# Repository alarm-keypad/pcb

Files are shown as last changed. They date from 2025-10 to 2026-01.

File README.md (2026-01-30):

# Alarm keypad PCB

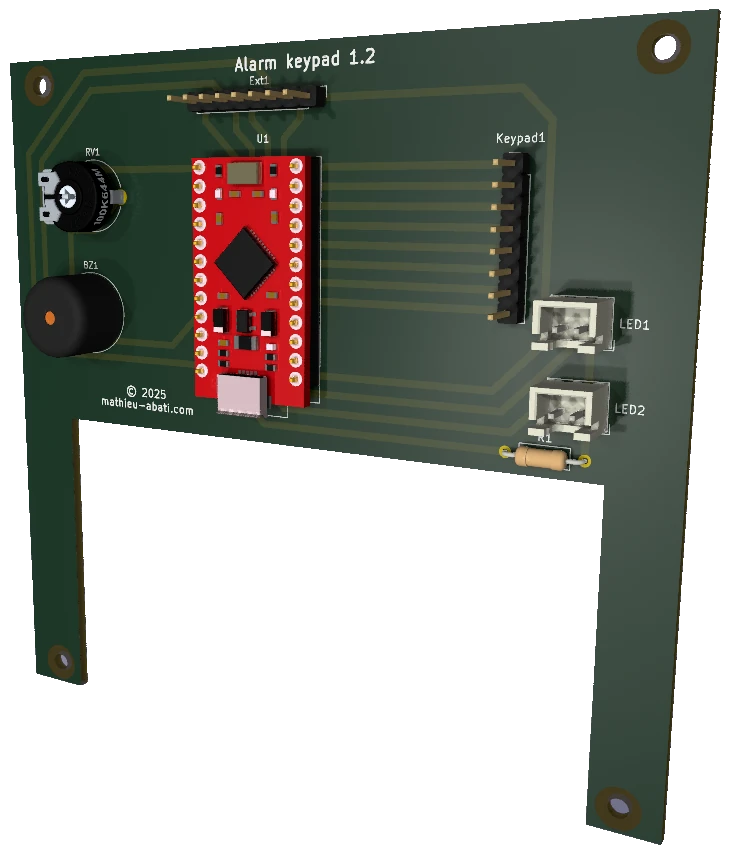
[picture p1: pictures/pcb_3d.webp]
PCB 3D view


KiCad project for alarm keypad PCB.

You can find a firmware designed to run on this board [on the dedicated repository](https://github.com/alarm-keypad/firmware).

## Required parts

- Resistor for LEDs (value depends on wanted brightness)
- Buzzer (active, 5V, model depends of wanted sound)
- Potentiometer for buzzer (to set sound level)
- Arduino Pro Micro (5V)
- 2x JST connector 1x02 2.50mm pitch (for case mounted LED)
- 2x 2.54mm 8 pins female connectors

## Integration

It is designed to be installed in an aluminium junction box 40x100x110mm.
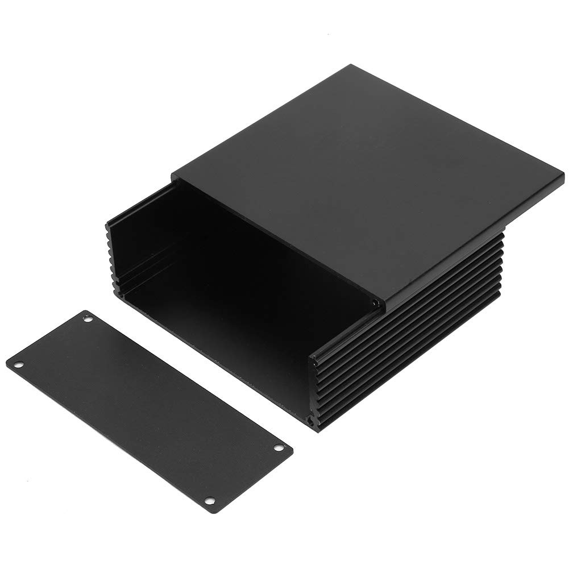
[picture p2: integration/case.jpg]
Case


You can use different kind of keypads, for example:
- Tru Components 4x3, or 4x4 (with A, B, C, D letters),
- Membrane matrix 4x4.

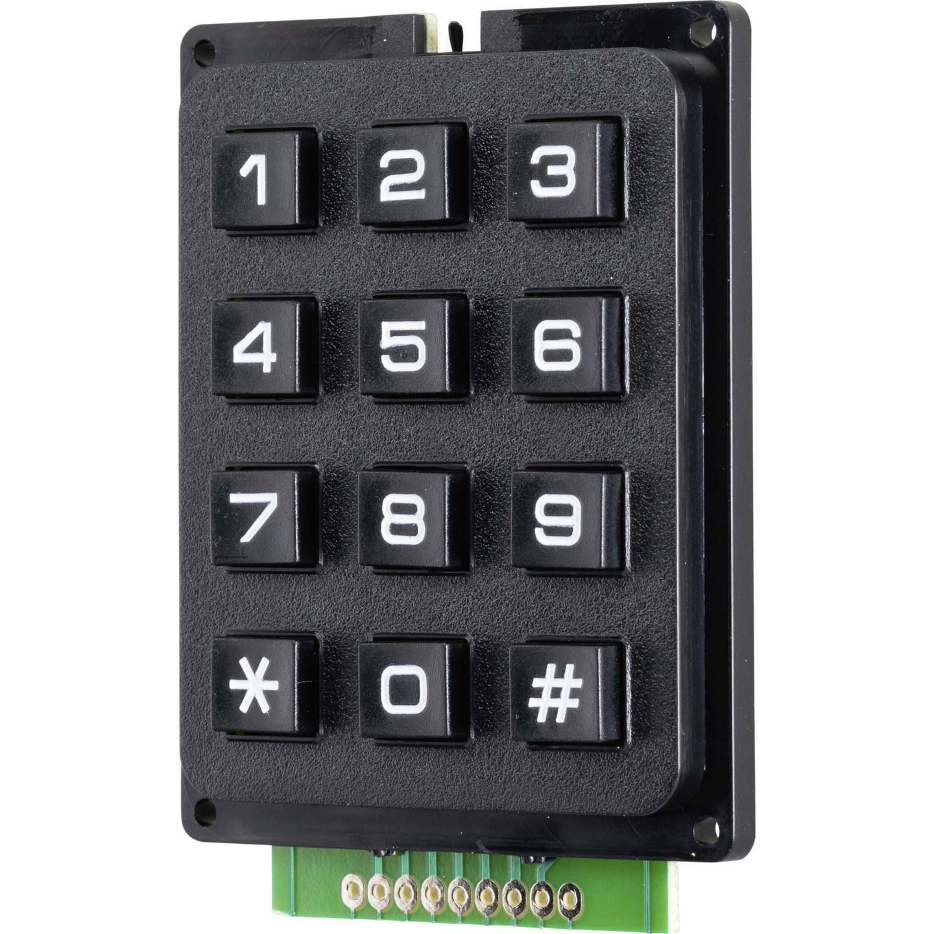
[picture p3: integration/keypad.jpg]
Tru Components 4x3

Tru Components 4x3 can be integrated in the case using the following resources.
See [drill and cut file](integration/keypad_drill_cut.pdf) to prepare the case.
Then you can use [this 3D printable border](integration/keypad_border.stl) to
make its integration clean.
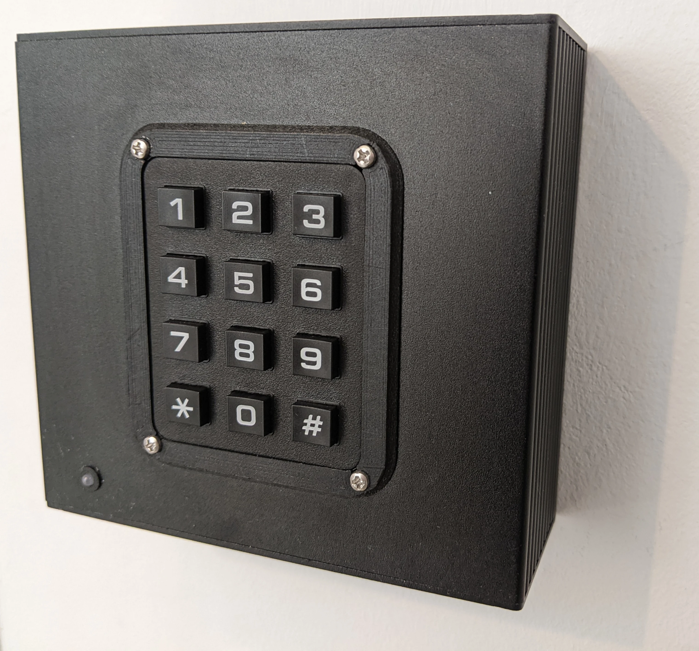
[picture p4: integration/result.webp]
Integration result


## KiCAD project

Arduino Pro Micro KiCAD files can be downloaded
[from this GitHub repository](https://github.com/g200kg/kicad-lib-arduino).

Piher PT-10 potentiometer 3D model can be downloaded
[from grabcad](https://grabcad.com/library/piher-pt-10-1).
Its scale has to be divided by 10.

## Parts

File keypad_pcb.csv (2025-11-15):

Source: | /home/mathieu/Documents/HomeAssistant/keypad/cad/keypad_pcb/keypad_pcb.kicad_sch
Date: | ven. 07 avril 2023 15:16:09
Tool: | Eeschema (6.0.9)
Generator: | /usr/share/kicad/plugins/bom_csv_grouped_by_value.py
Component Count: | 8
Individual Components:
Item | Qty | Reference(s) | Value | LibPart | Footprint | Datasheet
 |  | A1 | Arduino_Nano_v3.x | MCU_Module:Arduino_Nano_v3.x | Module:Arduino_Nano | http://www.mouser.com/pdfdocs/Gravitech_Arduino_Nano3_0.pdf
 |  | BZ1 | Buzzer | Device:Buzzer | Buzzer_Beeper:Buzzer_12x9.5RM7.6 | ~
 |  | Ext1 | Conn_01x08 | Connector_Generic:Conn_01x08 | Connector_PinHeader_2.54mm:PinHeader_1x08_P2.54mm_Vertical | ~
 |  | Keypad1 | Conn_01x08 | Connector_Generic:Conn_01x08 | Connector_PinHeader_2.54mm:PinHeader_1x08_P2.54mm_Vertical | ~
 |  | LED1 | Conn_01x02 | Connector_Generic:Conn_01x02 | Connector_JST:JST_XH_B2B-XH-A_1x02_P2.50mm_Vertical | ~
 |  | LED2 | Conn_01x02 | Connector_Generic:Conn_01x02 | Connector_JST:JST_XH_B2B-XH-A_1x02_P2.50mm_Vertical | ~
 |  | R1 | R | Device:R | Resistor_THT:R_Axial_DIN0207_L6.3mm_D2.5mm_P10.16mm_Horizontal | ~
 |  | RV1 | R_Potentiometer | Device:R_Potentiometer | Potentiometer_THT:Potentiometer_Piher_PT-10-V10_Vertical | ~
Collated Components:
Item | Qty | Reference(s) | Value | LibPart | Footprint | Datasheet
1 | 1 | A1 | Arduino_Nano_v3.x | MCU_Module:Arduino_Nano_v3.x | Module:Arduino_Nano | http://www.mouser.com/pdfdocs/Gravitech_Arduino_Nano3_0.pdf
2 | 1 | BZ1 | Buzzer | Device:Buzzer | Buzzer_Beeper:Buzzer_12x9.5RM7.6 | ~
3 | 2 | Ext1, Keypad1 | Conn_01x08 | Connector_Generic:Conn_01x08 | Connector_PinHeader_2.54mm:PinHeader_1x08_P2.54mm_Vertical | ~
4 | 2 | LED1, LED2 | Conn_01x02 | Connector_Generic:Conn_01x02 | Connector_JST:JST_XH_B2B-XH-A_1x02_P2.50mm_Vertical | ~
5 | 1 | R1 | R | Device:R | Resistor_THT:R_Axial_DIN0207_L6.3mm_D2.5mm_P10.16mm_Horizontal | ~
6 | 1 | RV1 | R_Potentiometer | Device:R_Potentiometer | Potentiometer_THT:Potentiometer_Piher_PT-10-V10_Vertical | ~

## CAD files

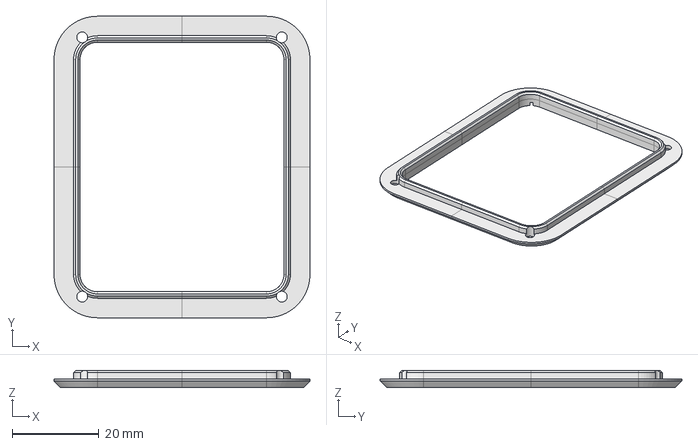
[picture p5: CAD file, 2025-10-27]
integration/keypad_border.FCStd
59.0 x 69.5 x 4.00 mm

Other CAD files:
integration/keypad_border.stl

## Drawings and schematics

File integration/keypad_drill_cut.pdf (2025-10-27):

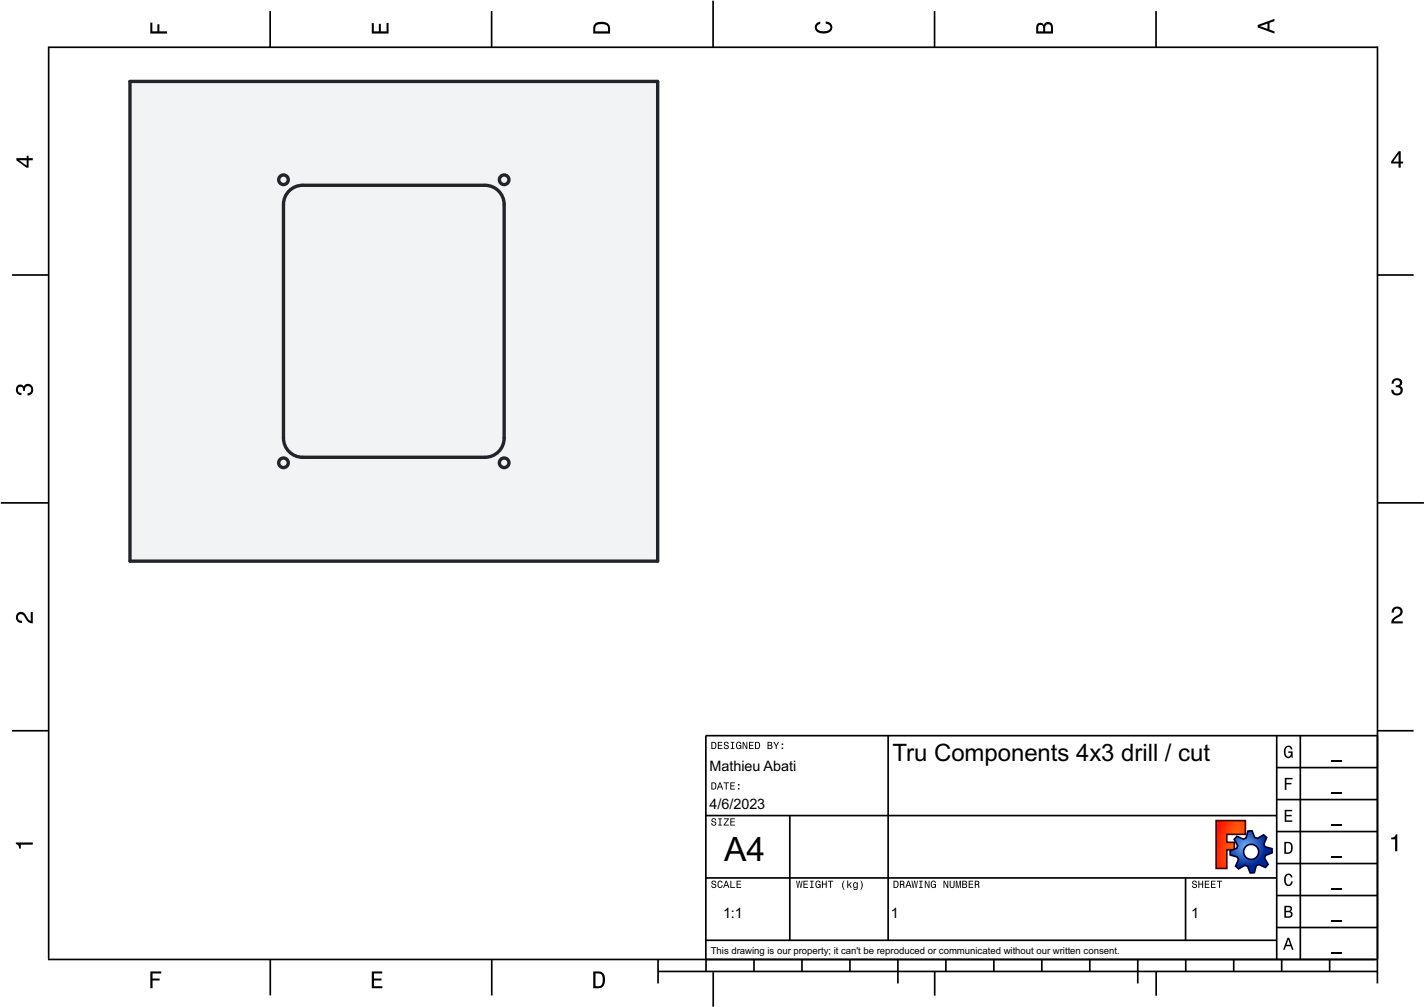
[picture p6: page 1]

Mathieu Abati 4/6/2023 | Tru Components 4x3 drill / cut

This drawing is our property; it can't be reproduced or communicated without our written consent.

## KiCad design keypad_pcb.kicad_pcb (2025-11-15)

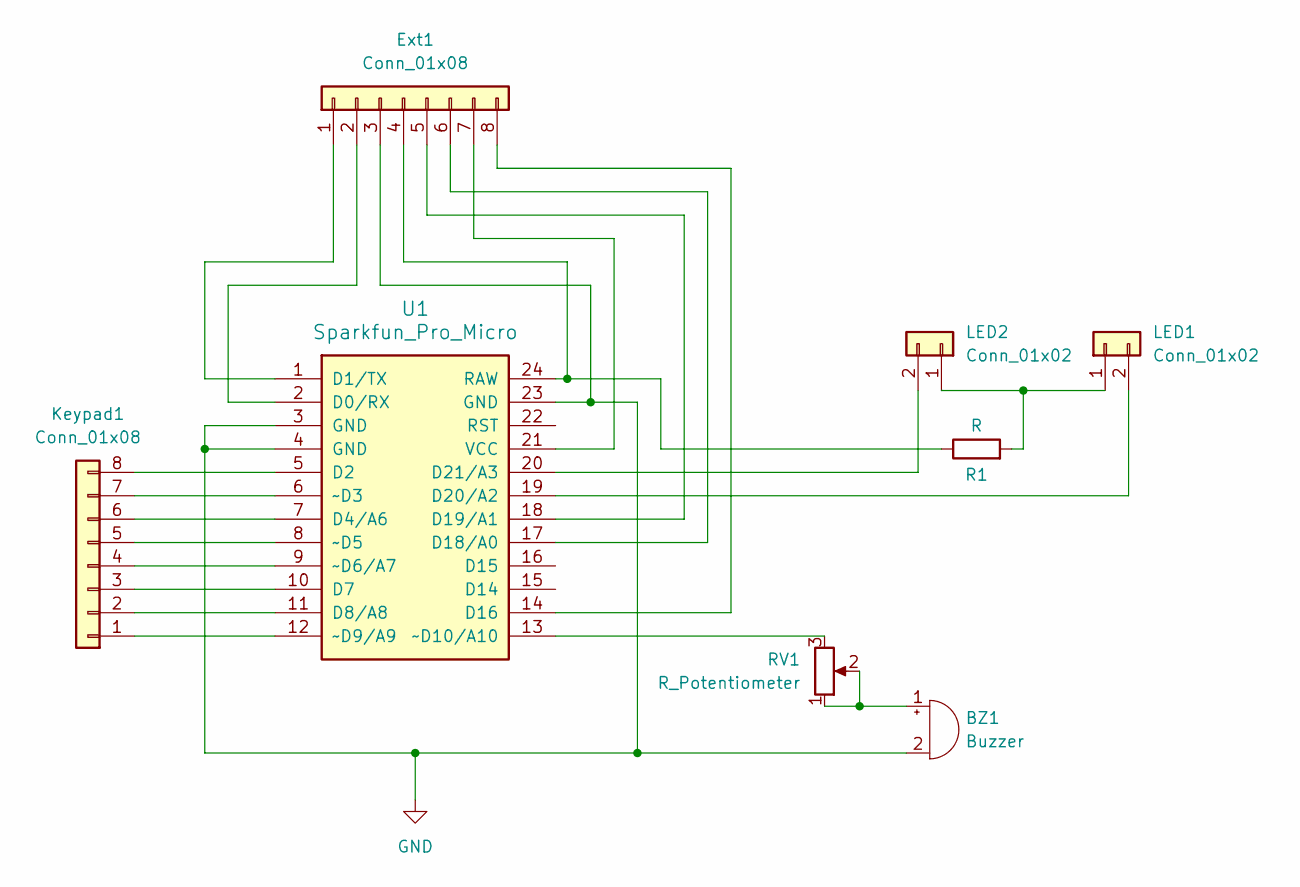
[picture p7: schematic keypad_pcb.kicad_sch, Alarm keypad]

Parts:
BZ1: Buzzer; Buzzer_12x9.5RM7.6
Ext1: Conn_01x08; PinHeader_1x08_P2.54mm_Vertical
Keypad1: Conn_01x08; PinHeader_1x08_P2.54mm_Vertical
LED1, LED2: Conn_01x02; JST_XH_B2B-XH-A_1x02_P2.50mm_Vertical
R1: R; R_Axial_DIN0207_L6.3mm_D2.5mm_P10.16mm_Horizontal
RV1: R_Potentiometer; Potentiometer_Piher_PT-10-V10_Vertical_Hole
U1: Sparkfun_Pro_Micro

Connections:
GND: BZ1.2 (+), Ext1.3, U1.3 (GND), U1.4 (GND), U1.23 (GND)
unnamed: BZ1.1 (-), RV1.1, RV1.2
unnamed: Ext1.1, U1.1 (D1/TX)
unnamed: Ext1.2, U1.2 (D0/RX)
unnamed: Ext1.4, R1.1, U1.24 (RAW)
unnamed: Ext1.5, U1.18 (D19/A1)
unnamed: Ext1.6, U1.17 (D18/A0)
unnamed: Ext1.7, U1.21 (VCC)
unnamed: Ext1.8, U1.14 (D16)
unnamed: Keypad1.1, U1.12 (~D9/A9)
unnamed: Keypad1.2, U1.11 (D8/A8)
unnamed: Keypad1.3, U1.10 (D7)
unnamed: Keypad1.4, U1.9 (~D6/A7)
unnamed: Keypad1.5, U1.8 (~D5)
unnamed: Keypad1.6, U1.7 (D4/A6)
unnamed: Keypad1.7, U1.6 (~D3)
unnamed: Keypad1.8, U1.5 (D2)
unnamed: LED1.1, LED2.1, R1.2
unnamed: LED1.2, U1.19 (D20/A2)
unnamed: LED2.2, U1.20 (D21/A3)
unnamed: RV1.3, U1.13 (~D10/A10)

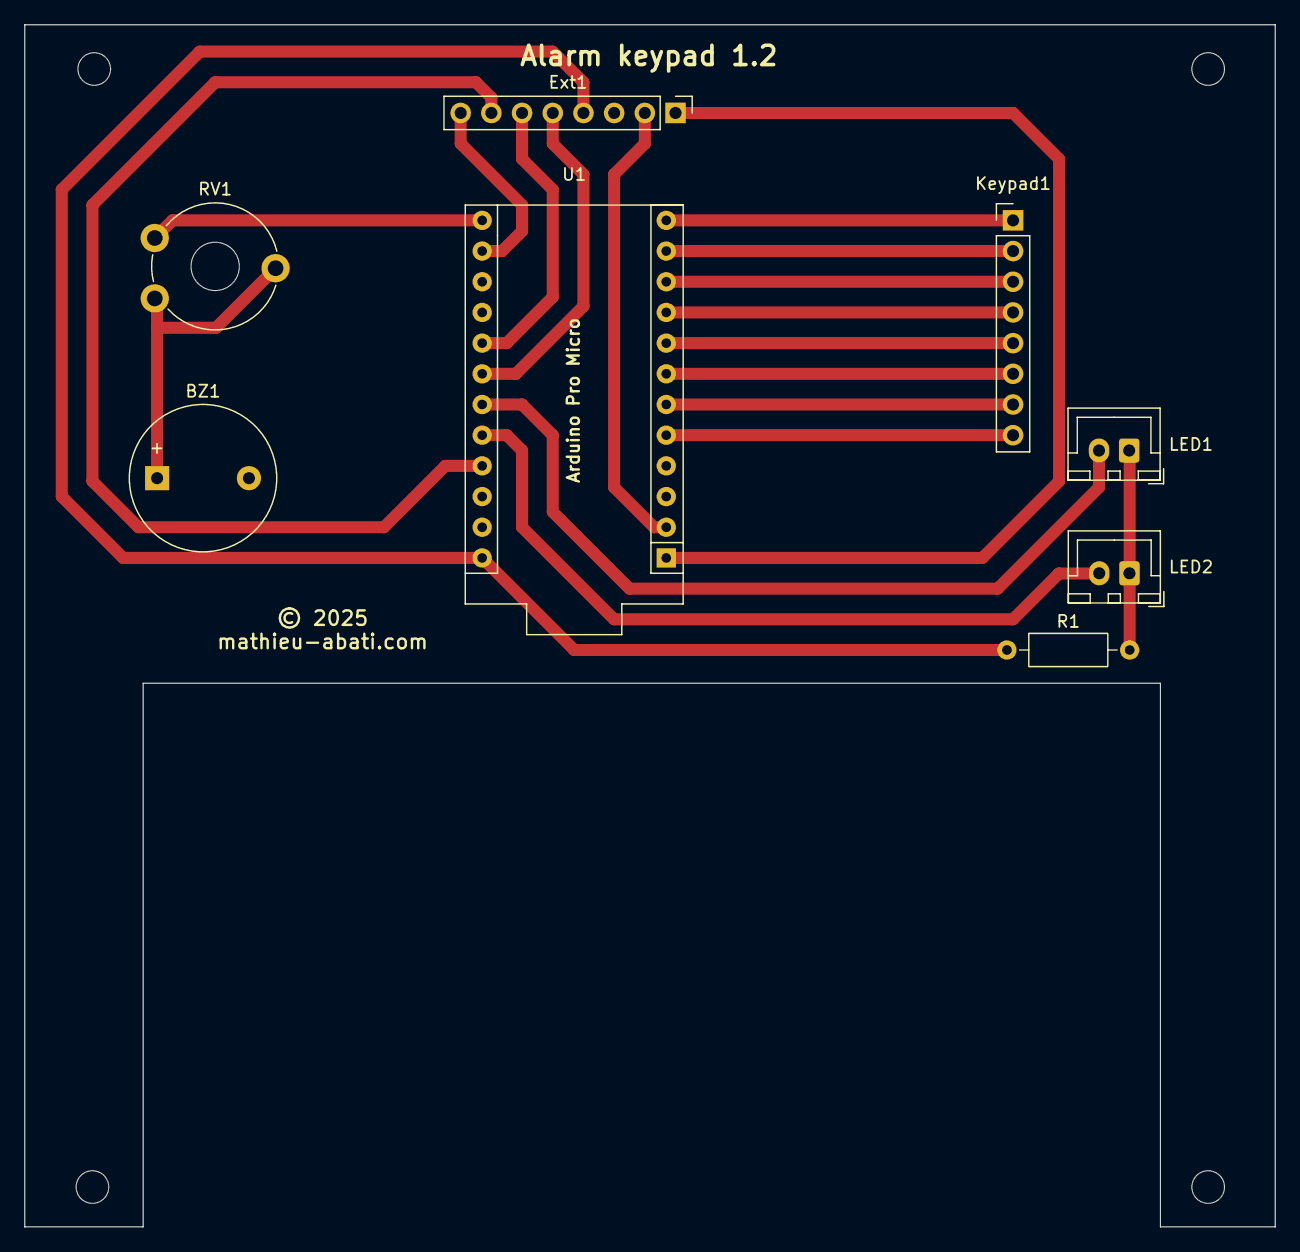
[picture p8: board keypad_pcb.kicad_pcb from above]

Board: 2 copper layers, 103.5 x 99.5 mm, 9 parts (1 on the bottom side), 21 nets.

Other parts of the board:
G1: LOGO; qr

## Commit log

2025-10-27 First release
    [keypad_border.FCStd, keypad_border.stl, keypad_pcb.kicad_pcb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]
2025-11-15 Rework for Arduino Pro Micro
    [keypad_pcb.csv, keypad_pcb.kicad_pcb, keypad_pcb.kicad_sch]
2025-11-15 Update potentiometer to add PCB hole and integrate 3D shape
    [keypad_pcb.kicad_pcb, keypad_pcb.kicad_sch]
2025-11-15 Fixes to be ready to generate gerber
    [keypad_pcb.kicad_pcb]

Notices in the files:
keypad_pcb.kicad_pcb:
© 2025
